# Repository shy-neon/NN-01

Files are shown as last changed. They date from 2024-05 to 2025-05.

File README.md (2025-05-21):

# NN-01
IR bridge based on attiny-85
</br>
</br>
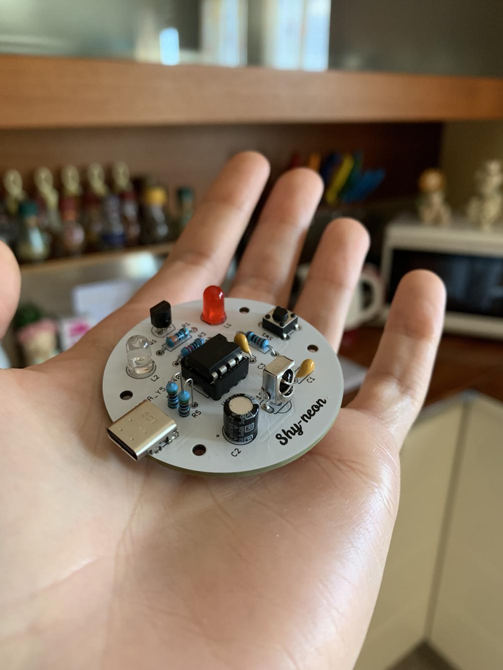
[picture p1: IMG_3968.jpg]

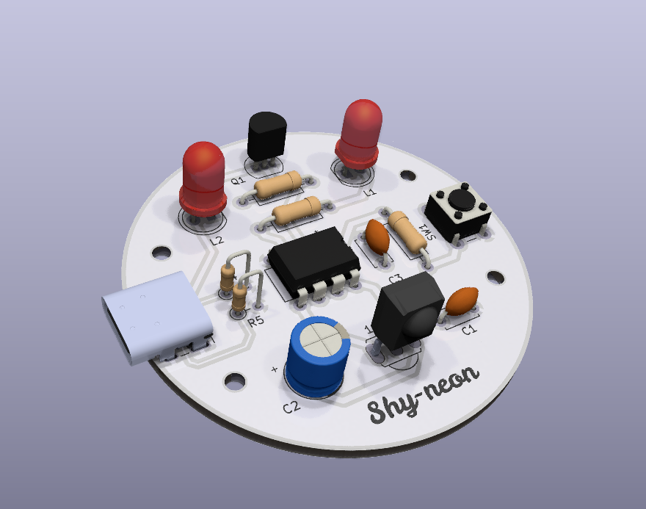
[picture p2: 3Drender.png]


</br>

## Description 
Imagine having different IR devices (e.g. a TV and an Home theatre hoked to it) each of them controlled by its own remote. This device allows you to control both of them with the same remote.
It can be field programmed (according to the flow diagram below) to emit a specific IR commad whenever a source IR command is recived, this can be useful to automate some scenarios (like turnig on the home theatre whenever the tv is turned on or controlling the volume from the TV remote).
This is expecially usefull when a generic universal remote cannot be used (modern smart TVs come with remotes which have oddly specific buttons for menus and so on...)
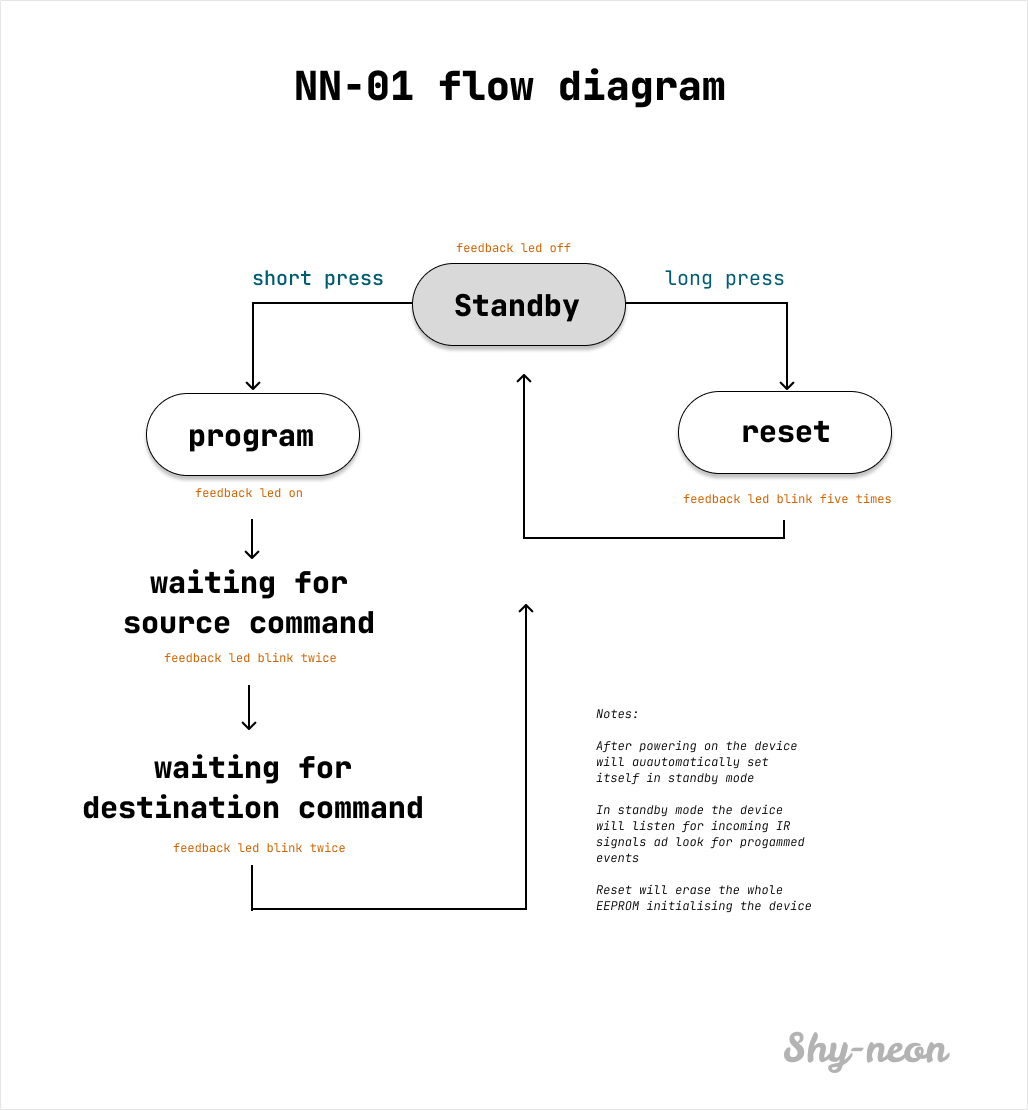
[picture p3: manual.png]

</br>
Repo provides the firmware (compatible with attiny 84, to be compiled with attinyCore), schematic and PCB layouts
</br>

### Partlist
1x 100uF - 16v electrolitic capacitor <a>> </br>
2x 0.1uF - ceramic capacitor </br>
1x GTC usb-c recepticle  <a href="https://www.digikey.it/it/products/detail/gct/USB4085-GF-A/9859662">available here </a> </br>
1x Atmel attiny 84 <a href="https://www.digikey.it/it/products/detail/microchip-technology/ATTINY85-20PU/735469">available here </a> </br> 
1x 1838 ir receiver </br>
1x 940/850 nm ir LED (at least 60°) <a href="https://www.digikey.it/it/products/detail/vishay-semiconductor-opto-division/TSAL7600/1681341">available here </a> </br>
1x red or visible LED  </br>
1x 330 ohm Resistor   </br>
1x 10k ohm Resistor   </br>
1x 220 ohm Resistor   </br>

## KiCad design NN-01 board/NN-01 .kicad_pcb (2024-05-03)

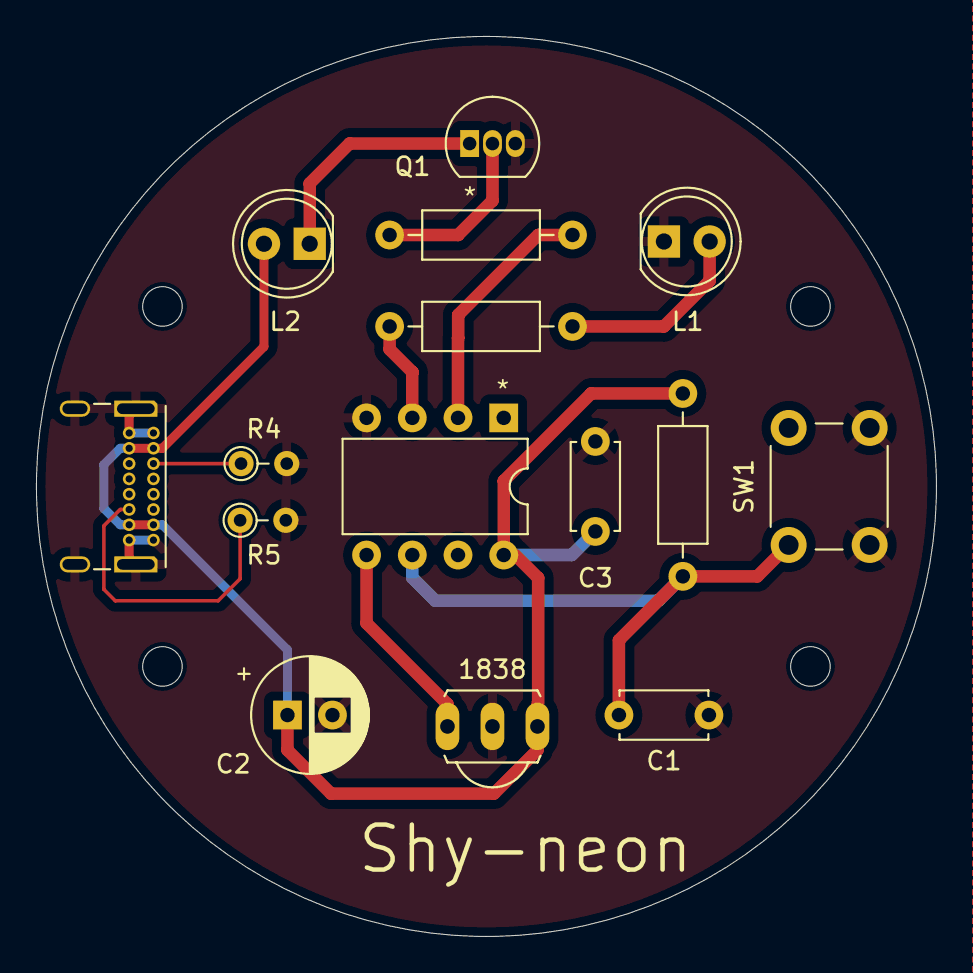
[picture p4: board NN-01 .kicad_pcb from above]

Board: 2 copper layers, 50.0 x 50.0 mm, 15 parts (0 on the bottom side), 11 nets.

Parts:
C1: 0.1u; C_Disc_D4.7mm_W2.5mm_P5.00mm
C2: C; CP_Radial_D6.3mm_P2.50mm
C3: C; C_Disc_D4.7mm_W2.5mm_P5.00mm
D1, D2: LED; LED_D5.0mm
J2: USB4085-GF-A_REVB; USB_C_Receptacle_GCT_USB4085
Q1: BC337; TO-92_Inline
R1: 220; R_Axial_DIN0207_L6.3mm_D2.5mm_P10.16mm_Horizontal
R2: 10k; R_Axial_DIN0207_L6.3mm_D2.5mm_P10.16mm_Horizontal
R3: 330; R_Axial_DIN0207_L6.3mm_D2.5mm_P10.16mm_Horizontal
R4, R5: R; R_Axial_DIN0204_L3.6mm_D1.6mm_P2.54mm_Vertical
SW1: SW_Push_Dual_x2; SW_PUSH_6mm_H4.3mm
U1: ATtiny85-20P; DIP-8_W7.62mm
U2: TSOP1838; TSOP18XX

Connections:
GND: C1.2, C2.2, C3.2, D2.1 (K), J2.A1 (GND), J2.A12 (GND__1), J2.B1 (GND__2), J2.B12 (GND__3), J2.S1 (SHELL), Q1.3 (E), R4.2, R5.2, SW1.2 (D), U1.4 (GND), U2.GND
unnamed: D1.1 (K), Q1.1 (C)
unnamed: D2.2 (A), R3.2
unnamed: J2.A5 (CC1), R4.1
unnamed: J2.B5 (CC2), R5.1
unnamed: Q1.2 (B), R1.1
unnamed: C1.1, R2.1, SW1.1 (C), U1.6 (PB1)
unnamed: U1.5 (AREF/PB0), U2.OUT
unnamed: R1.2, U1.2 (XTAL1/PB3)
unnamed: R3.1, U1.3 (XTAL2/PB4)
VCC: C2.1, C3.1, D1.2 (A), J2.A4 (VBUS), J2.A9 (VBUS__1), J2.B4 (VBUS__2), J2.B9 (VBUS__3), R2.2, U1.8 (VCC), U2.VCC (V+)

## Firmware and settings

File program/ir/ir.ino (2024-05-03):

#define DECODE_SONY
#define DECODE_SAMSUNG
#define DECODE_NEC


#include <stdlib.h>

#define LED_PIN PB4 

#include <IRremote.h>
#include <EEPROM.h>
#include <avr/io.h>

#define INT_PIN PB1 
#define INTERRUPT_PIN PCINT1
#include <avr/interrupt.h>
#define PCINT_VECTOR PCINT0_vect  

int mode = 1;
bool lastState = true;


typedef struct{
  IRData source;
  IRData destination;
} command;

command last;
command current;

void setup() {
  pinMode(4, OUTPUT);
  IrSender.begin(2);
  IrReceiver.begin(0, DISABLE_LED_FEEDBACK);
  
  cli();                            // Disable interrupts during setup
  PCMSK |= (1 << INTERRUPT_PIN);    // Enable interrupt handler (ISR) for our chosen interrupt pin (PCINT1/PB1/pin 6)
  GIMSK |= (1 << PCIE);             // Enable PCINT interrupt in the general interrupt mask
  pinMode(INT_PIN, INPUT_PULLUP);   // Set our interrupt pin as input with a pullup to keep it stable
  sei();  
}

void loop() {
  if(mode == 0){
    choseFunction();
  } else {
    if(IrReceiver.decode()){
      current = lookup(IrReceiver.decodedIRData);
      if(current.source.address != 0){
        IrSender.sendSamsung(current.destination.address, current.destination.command, 3);
      }
    }
    IrReceiver.resume();
  }
}

ISR(PCINT_VECTOR)
{
  if( digitalRead(INT_PIN) == LOW ) {
    changeMode();
  }
}

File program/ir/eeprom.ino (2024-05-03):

void writeCommand(command data){
  command current;
  for(int address = 0; address < (EEPROM.length() - sizeof(command)); address=address+sizeof(command)){
    EEPROM.get(address, current);
    if (current.source.address == 0x00){
      EEPROM.put(address, data);
      blinkLED(2, 100);
      return;
    }
  }
  blinkLED(10, 100);
}


void erase () {
  for (int i = 0 ; i < EEPROM.length() ; i++) {
    EEPROM.update(i, 0);
  }
  blinkLED(10, 100);
}

command lookup (IRData data) {
  command current;
  for(int address = 0; address < (EEPROM.length() - sizeof(command)); address=address+sizeof(command)){
    EEPROM.get(address, current);
    if(compare(data, current)){
      //Serial.println("found");
      blinkLED(1, 100);
      return current;
    } else {
      current.source.address == 0;
    }
  }
}
